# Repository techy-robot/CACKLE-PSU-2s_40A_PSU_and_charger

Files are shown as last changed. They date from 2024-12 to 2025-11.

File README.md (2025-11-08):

---
modified: 2025-11-07T22:09:08-07:00
---

# 2s 40A PSU and charger

> [!TIP]
> This board is part of a larger modular control board ecosystem, [CACKLE](https://github.com/techy-robot/CACKLE)

This is a rather complex power supply unit. It supports USB-C Power Delivery at 9volt 2 amps, and can charge a 2 cell lipo battery. It can pump out 40 amps if the battery supports the current. It also had battery protection and balancing built in, and a RS485 communication unit that can translate USB or SPI data to RS485.

The outer copper is 2oz, and the inner is 0.5 oz. Additional metal is needed to support the full current.

The main ICs on board are the TI BQ24780S battery charger, TI BQ76905 battery balancer and monitor, and a CH32X035G8U6 mcu. The system can theoretically handle 20 volt spikes, but the battery and all down line items could become damaged. I think there is also some 16v capacitors on the power lines that would be damaged. This is really meant for 9v usb-c charging to an 8.4v max lipo.

There are 2 plated through hole pads for the main battery wires, and a JST XH 3-pin connector for the balance plug in the common pin arrangement for Turnigy batteries.

The MCU has several purposes:
- Manage USB-C PD negotiations over the CC pins (built in PHY)
- Interact with the battery charger to keep it alive and change settings for charge profiles and curves
- Trigger battery balancing
- Report battery sensor data over the bus
- Act as a host adapter to convert USB or SPI data to rs485 bus commands and back. Helpful for debugging the system via a laptop, or if your main compute board needs to control the motors and sensors and doesn't have RS485 built in.

Schematic PDF

Partial 3D image, some connectors missing:
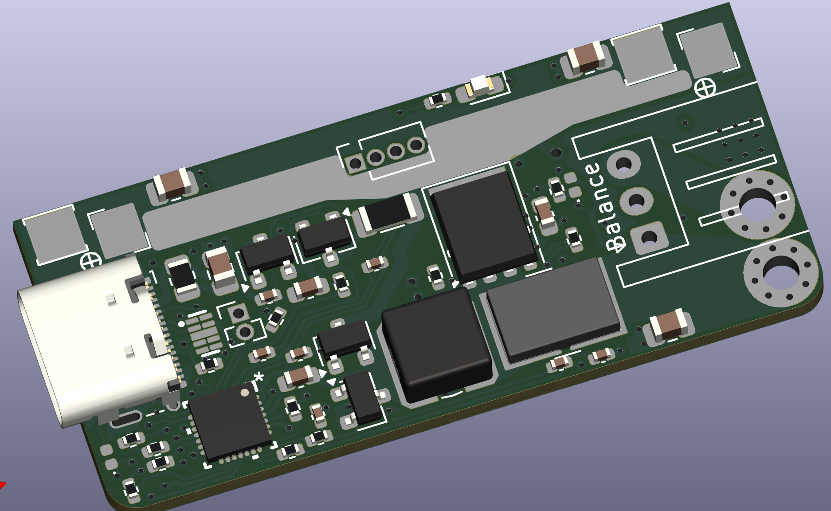
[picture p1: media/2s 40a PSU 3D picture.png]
2s 40a PSU 3D picture


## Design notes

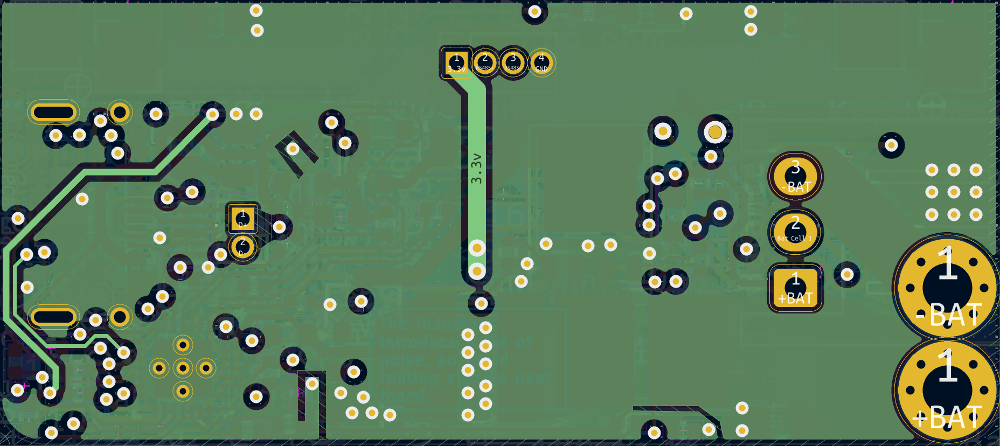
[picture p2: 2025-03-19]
media/2s 40a PSU In1.png

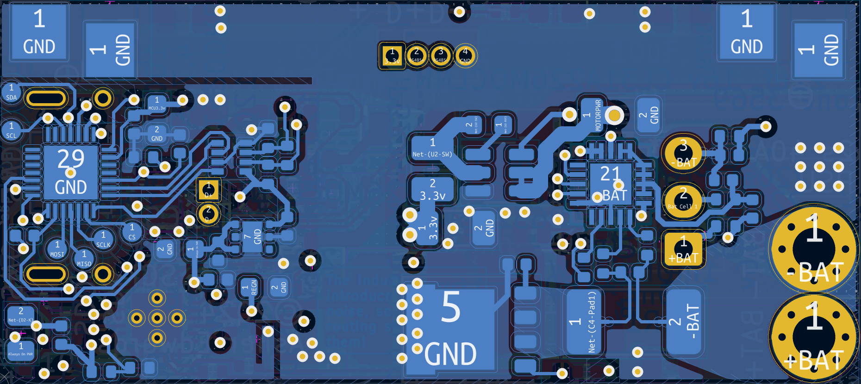
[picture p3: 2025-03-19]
media/2s 40a PSU Bottom.png

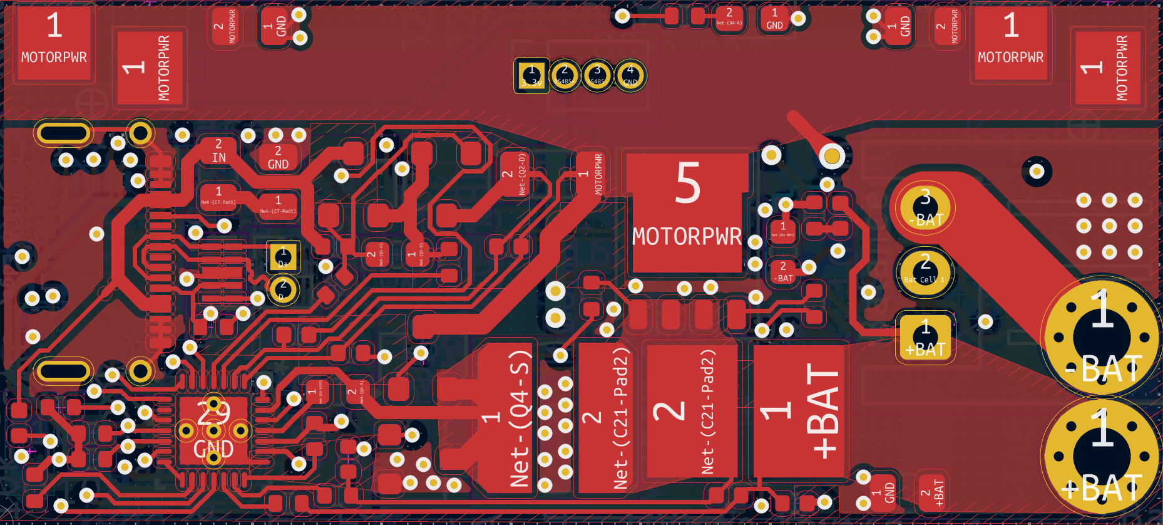
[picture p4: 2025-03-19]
media/2s 40a PSU Top.png

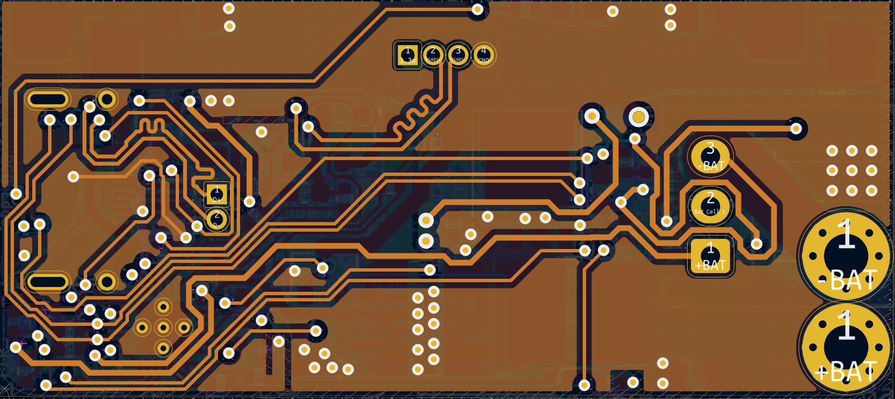
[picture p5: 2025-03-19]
media/2s 40a PSU In2.png

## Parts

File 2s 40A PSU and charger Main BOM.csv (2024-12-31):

Id | Designator | Footprint | Quantity | Designation | Supplier and ref
1 | R14 | R_2512_6332Metric_6W | 1 | 1mOhm, 6W
2 | R18 | R_Vishay_2818 | 1 | 5mOhm, 10W, 2818
3 | C9,C23,C10,C21,C11,C22,C32,C25,C4,C3 | C_0402_1005Metric | 10 | 100nF, 16v
4 | D11 | CDDFN103324P | 1 | CDDFN10-3324P
5 | R24,R20,R23,R29,R11 | R_0402_1005Metric | 5 | 10k
6 | R10,R8,R7 | R_0402_1005Metric | 3 | 4.02k
7 | C20,C12,C7,C14 | C_0805_2012Metric | 4 | 10uF, 16v
8 | R1 | R_1206_3216Metric | 1 | 10mOhm, 1W
9 | Q1,Q5,Q4,Q2 | SC-59 | 4 | PJA3430, or HL 2320A
10 | D1,D3,D2 | D_0402_1005Metric | 3 | GSDH3005
11 | R19,R6,R33 | R_0402_1005Metric | 3 | 5.1k
12 | C2,C24 | C_0603_1608Metric | 2 | 2.2uf, 16v
13 | R25 | R_0402_1005Metric | 1 | 80.6 ohm
14 | C5 | C_0402_1005Metric | 1 | 1nF, 16v
15 | J3,J1,J7,J6 | Keystone_3579 | 4 | Keystone 3579
16 | R3,R5,R4 | R_0402_1005Metric | 3 | 100ohm
17 | L2 | L_Bourns_SDR0604 | 1 | 6.8uH HPC HPC5040NF-6R8M
18 | J2 | JST_XH_S3B-XH-A_1x03_P2.50mm_Horizontal | 1 | JST XH-S Balance Plug
19 | J5,J4,J8,J9 | Keystone_3569_half | 4 | Keystone 3569
20 | J11 | PinSocket_1x04_P1.27mm_Vertical | 1 | 1.27mm 4 pin socket
21 | R2 | R_0805_2012Metric | 1 | 2ohm
22 | R21,R12,R22,R16,R17,R15 | R_0402_1005Metric | 6 | 10ohm
23 | D4 | LED_0603_1608Metric_Pad1.05x0.95mm_HandSolder | 1 | 2.6~3.1 Fv Green 5ma
24 | Q3,Q6 | PQFN-8-EP_6x5mm_P1.27mm_Generic | 2 | Vishay sir404dp, or SiR500DP
25 | U3 | RUY0028A | 1 | BQ24780SRUYR
26 | C6,C17 | C_0603_1608Metric | 2 | 47nF, 16v
27 | J10 | USB_C_G-Switch_GT-USB-7025-JLCPCBv | 1 | G-Switch-GT-USB-7025
28 | R30,R31 | R_0402_1005Metric | 2 | 866k
29 | U7 | WSON-6-1EP_2x2mm_P0.65mm_EP1x1.6mm | 1 | TPS7A2633DRV
30 | R26,R27,R28 | R_0402_1005Metric | 3 | 120 ohm
31 | C15 | C_0402_1005Metric | 1 | 1uf, 16v
32 | C28,C27 | C_1206_3216Metric | 2 | 22uf, 16v CL31A226MOCLNN
33 | C31 | C_0603_1608Metric | 1 | 10uF, 16v
34 | C40 | C_0603_1608Metric | 1 | 100nF, 16v
35 | U5 | SOT-583-8 | 1 | THVD1420DRLR
36 | C13,C19,C18 | C_0402_1005Metric | 3 | 220nF, 16v
37 | L3 | L_1008_2520Metric | 1 | 2.2uH, WIP322512A-2R2MLDG
38 | C30,C29 | C_0402_1005Metric | 2 | 100pF
39 | C33 | C_0402_1005Metric | 1 | 2.2uF, 16v
40 | U1 | VQFN20_RGR_TEX | 1 | BQ76905RGRR
41 | U6 | QFN-28-1EP_4x4mm_P0.4mm_EP2.8x2.8mm | 1 | CH32X035G8U6
42 | R9 | R_0805_2012Metric | 1 | 10ohm
43 | U2 | TSOT-23-6 | 1 | AP63203WU
44 | C26 | C_0603_1608Metric | 1 | 4.7uF, 16v

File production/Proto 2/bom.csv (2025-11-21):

Designator | Footprint | Quantity | Value | LCSC Part #
C10, C11, C21, C22, C23, C25, C3, C32, C4, C9 | 0402 | 10 | 100nF, 16v | C1525
C12, C14, C20, C7 | 0805 | 4 | 10uF, 16v | C15850
C13, C18, C19 | 0402 | 3 | 220nF, 16v | C16772
C15 | 0402 | 1 | 1uf, 16v | C52923
C17, C6 | 0603 | 2 | 47nF, 16v | C1622
C2, C24 | 0603 | 2 | 2.2uf, 16v | C23630
C26 | 0603 | 1 | 4.7uF, 16v | C19666
C27, C28 | 1206 | 2 | 22uf, 16v CL31A226MOCLNN | C159758
C29, C30 | 0402 | 2 | 100pF | C1546
C31 | 0603 | 1 | 10uF, 16v | C96446
C33 | 0402 | 1 | 2.2uF, 16v | C12530
C40 | 0603 | 1 | 100nF, 16v | C14663
C5 | 0402 | 1 | 1nF, 16v | C1523
D1, D2, D3 | 0402 | 3 | GSDH3005 | C2837790
D11 | CDDFN103324P | 1 | CDDFN10-3324P | C913227
D4 | 0603 | 1 | 2.6~3.1 Fv Green 5ma | C3028858
J1, J3, J6, J7 | Keystone_6100 | 4 | Keystone 6100
J10 | USB_C_G-Switch_GT-USB-7025-JLCPCBv | 1 | G-Switch-GT-USB-7025 | C963213
J13 | Precidip 853-87-004-20-001101 | 1 | Precidip 853-87-004-20-001101
J2 | JST_XH_S3B-XH-A_1x03_P2.50mm_Horizontal | 1 | JST XH-S Balance Plug | C161860
J4, J5, J8, J9 | Keystone_6102 | 4 | Keystone 6102
L2 | L_Bourns_SDR0604 | 1 | 6.8uH HPC HPC5040NF-6R8M | C357072
L3 | 1008 | 1 | 3.3uH | C2041573
Q1, Q2, Q4, Q5 | SC-59 | 4 | PJA3430, or HL 2320A | C7437078
Q3, Q6 | PQFN-8-EP_6x5mm_P1.27mm_Generic | 2 | Vishay sir404dp, or SiR500DP | C3289487
R1 | 1206 | 1 | 10mOhm, 1W | C473031
R10, R7, R8 | 0402 | 3 | 4.02k | C43251
R11, R13, R20, R23, R24, R29, R32 | 0402 | 7 | 10k | C25744
R12, R15, R16, R17, R21, R22 | 0402 | 6 | 10ohm | C25077
R14 | 2512 | 1 | 1mOhm, 6W | C19270875
R18 | R_Vishay_2818 | 1 | 5mOhm, 10W, 2818 | C2090564
R19, R33, R6 | 0402 | 3 | 5.1k | C25905
R2 | 0805 | 1 | 2ohm | C17521
R25 | 0402 | 1 | 80.6 ohm | C185392
R26, R27, R28 | 0402 | 3 | 120 ohm | C25079
R3, R4, R5 | 0402 | 3 | 100ohm | C25076
R30, R31 | 0402 | 2 | 866k | C137931
R9 | 0805 | 1 | 10ohm | C17415
SW1 | R-667995_MIT | 1 | Mitsumi R-667996 | C4365007
U1 | VQFN20_RGR_TEX | 1 | BQ76905RGRR | C22394458
U2 | TSOT-23-6 | 1 | AP63203WU | C780769
U3 | RUY0028A | 1 | BQ24780SRUYR
U5 | SOT-583-8 | 1 | THVD1420DRLR
U6 | QFN-28-1EP_4x4mm_P0.4mm_EP2.8x2.8mm | 1 | CH32X035G8U6 | C7437027
U7 | WSON-6-1EP_2x2mm_P0.65mm_EP1x1.6mm | 1 | TPS7A2633DRV | C2876256

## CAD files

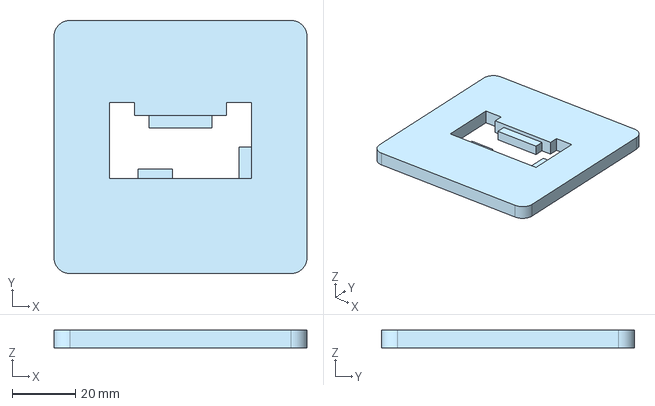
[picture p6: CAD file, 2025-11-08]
2s 40amp PSU 2nd side Stencil Jig.step
80.0 x 80.0 x 5.60 mm

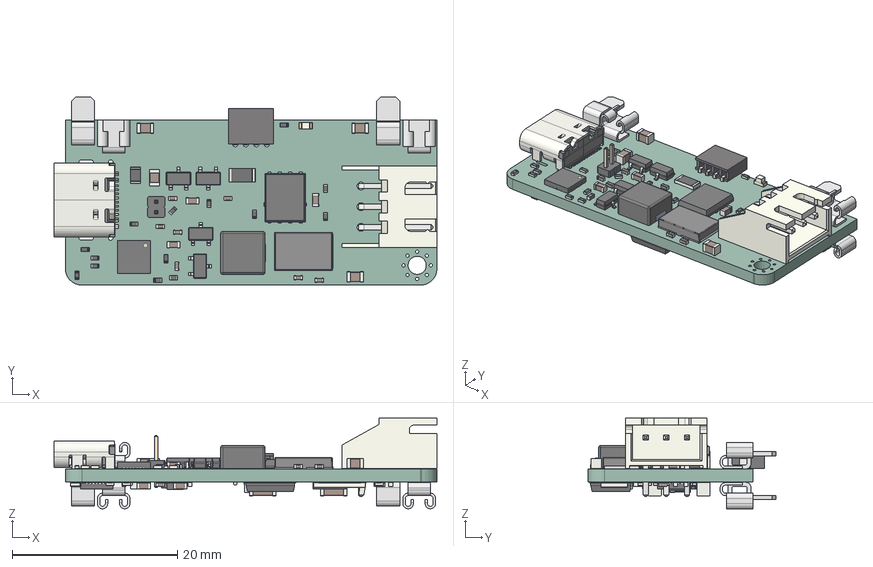
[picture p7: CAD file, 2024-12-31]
2s 40A PSU and charger.step
46.4 x 22.8 x 11.0 mm
C_0402_1005Metric x 18
R_0402_1005Metric x 26
C_0805_2012Metric x 4
R_1206_3216Metric
SC_59 x 4
C_0603_1608Metric x 7
Keystone 3579 x 4
WSHM2818
CQ assembly
JST_S3B_XH_A
Keystone 3569 half x 4
BD090-04-A-L-G
R_0805_2012Metric x 2
PinHeader_1x02_P127mm_Vertical
LED_0603_1608Metric
Vishay_PowerPAK_SO-8 x 2
QFN-28-1EP_4x4mm_Pitch0.4mm x 2
USB_C_Receptacle_16P_TopMnt_Horizontal_GCT_USB4105-xx-A
WSON_6_1EP_2x2mm_P065mm_EP1x16mm
C_1206_3216Metric x 2
SOT_563
L_1008_2520Metric
R_2512_6332Metric
QFN-20-1EP_4x4mm_Pitch0.5mm
TSOT_23_6
_autosave-2s 40A PSU and charger_PCB

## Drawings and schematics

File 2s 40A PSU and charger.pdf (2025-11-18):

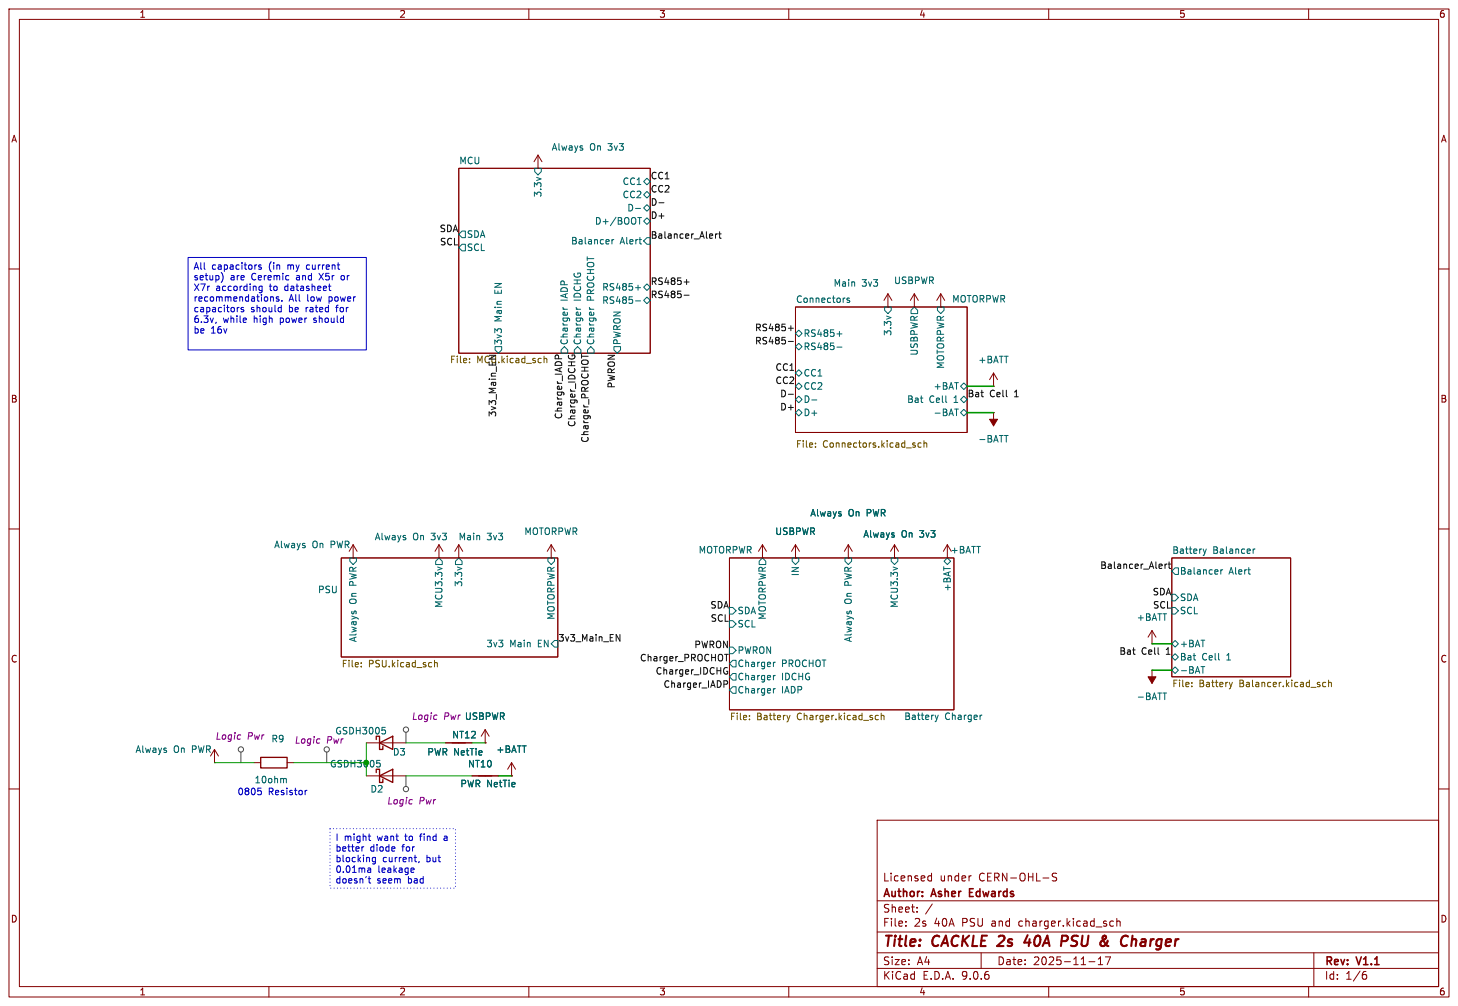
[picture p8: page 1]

D+/BOOT CC2 D- CC1 3v3 Main EN MCU

+BATT Main 3v3 Always On PWR

-BATT Always On 3v3 Main 3v3 D3 GSDH3005 D2 GSDH3005

Always On PWR MOTORPWR

Charger PROCHOT Charger IADP Charger IDCHG

I might want to find a

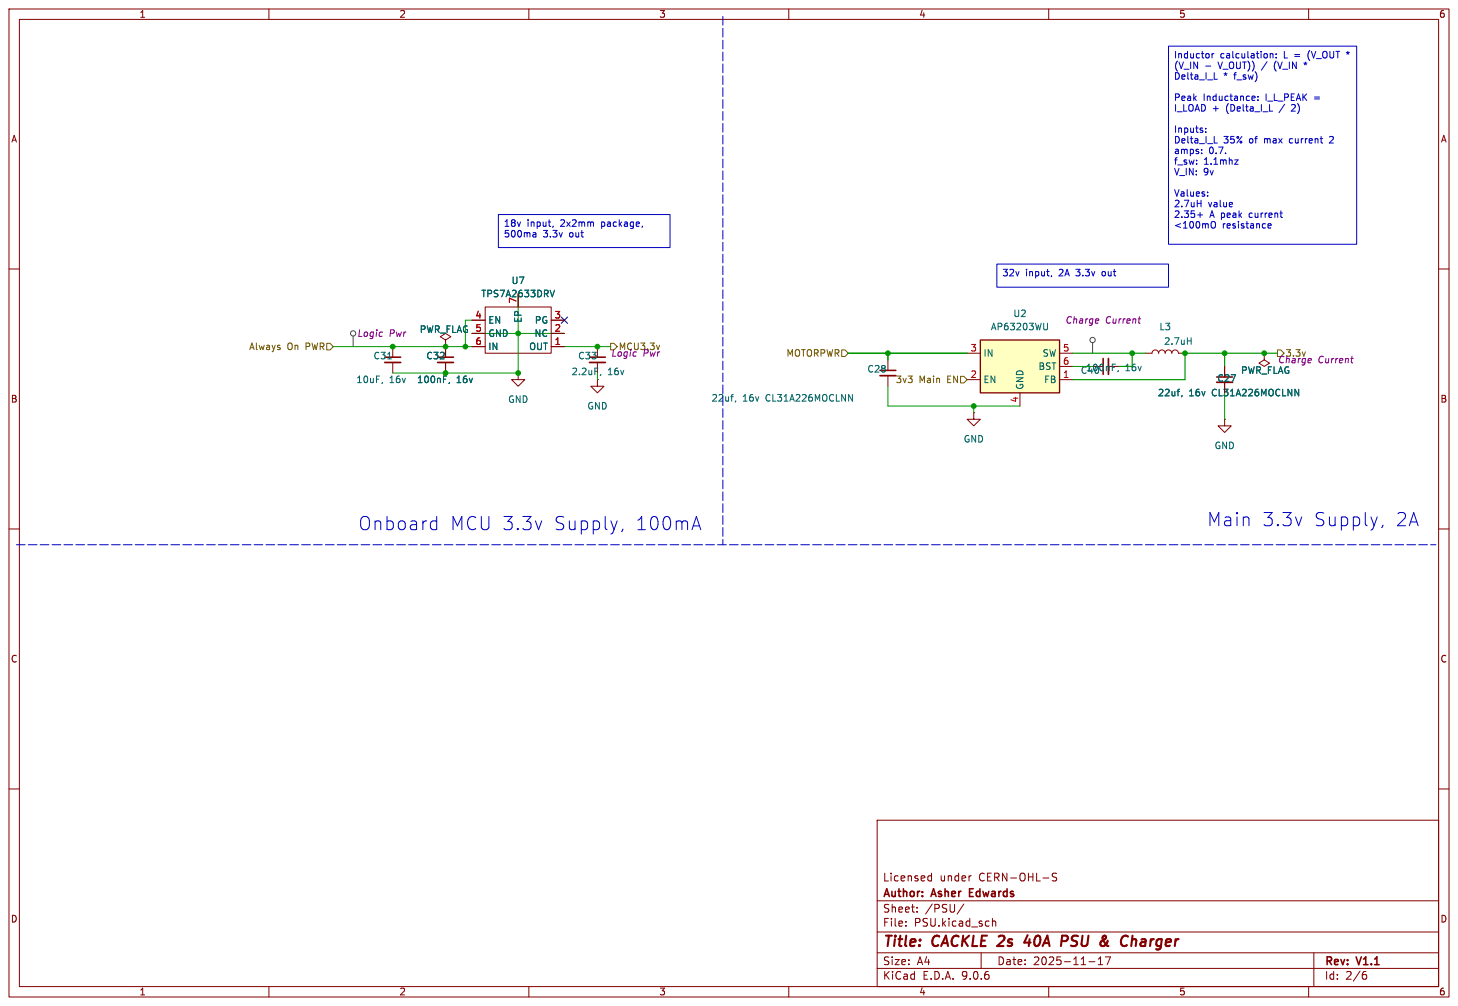
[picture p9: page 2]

Inputs: Delta_I_L 35% of max current 2

3.3v Charge Current MOTORPWR MCU3.3v Logic Pwr Always On PWR

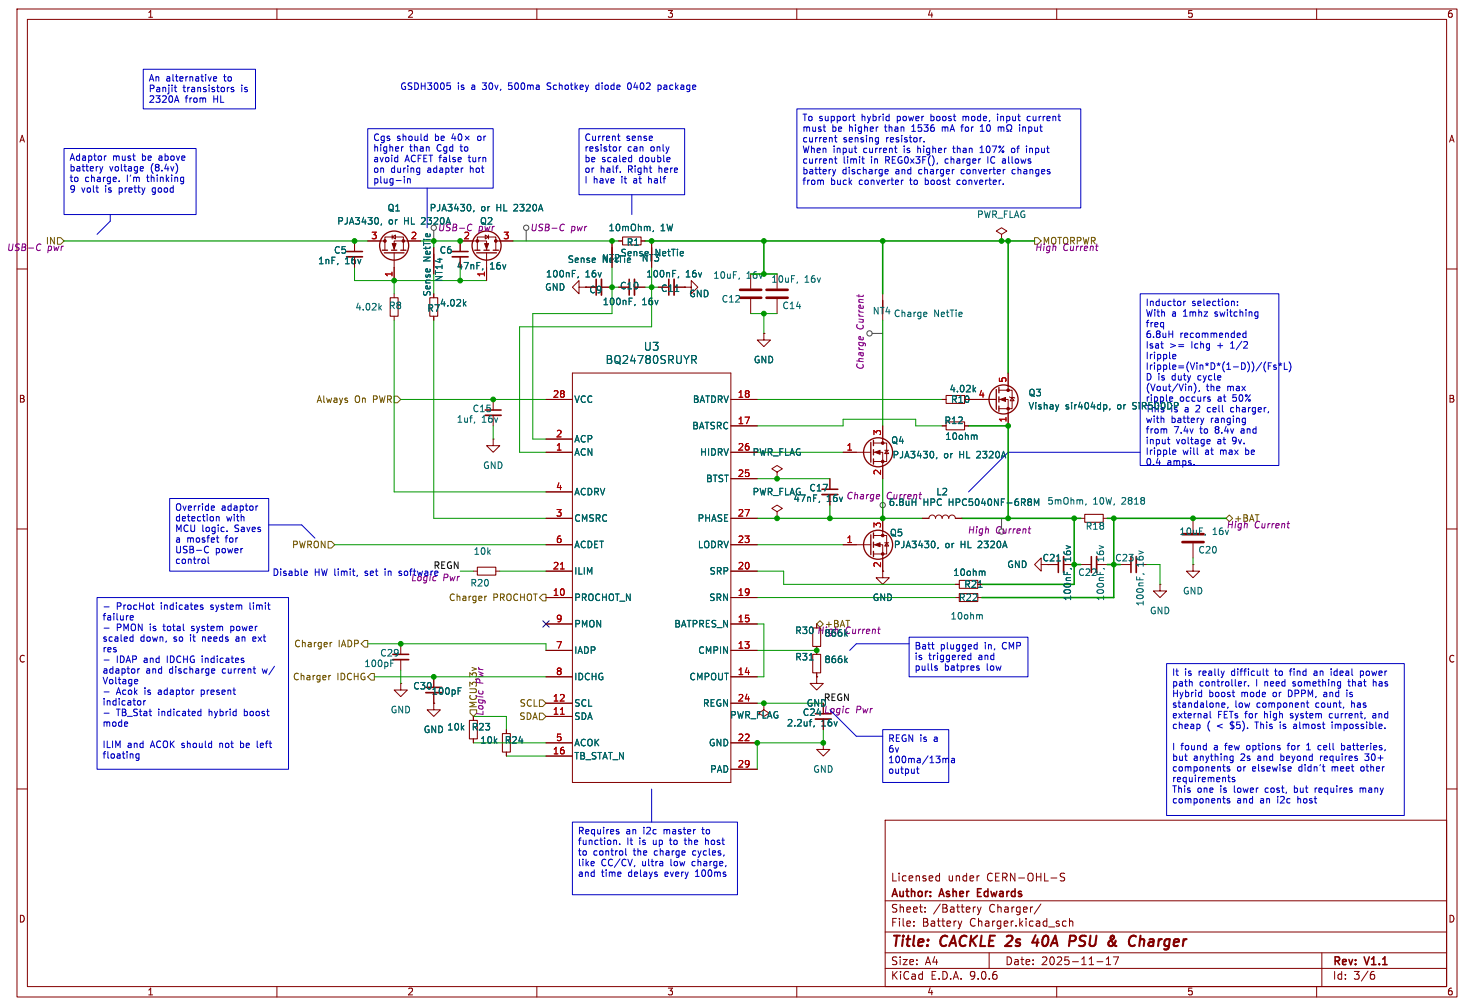
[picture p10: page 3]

I have it at half Requires an i2c master to

0.4 amps. Cgs should be þÿ40×or higher than Cgd to

Adaptor must be above
battery voltage (8.4v)
to charge. I'm thinking

avoid ACFET false turn
on during adapter hot plug-in
LODRV 23 SRP 20 SRN 19 BATPRES_N 15 CMPIN 13 CMPOUT 14 REGN 24 GND 22 PAD 29 HIDRV 26 U3 BQ24780SRUYR

or half. Right here

3 2 Q4PJA3430, or HL 2320A NT4 Charge NetTie C6

freq
6.8uH recommended
Isat >= Ichg + 1/2
Iripple
Iripple=(Vin*D*(1-D))/(Fs*L) D is duty cycle

ripple occurs at 50%
This is a 2 cell charger, with battery ranging

from 7.4v to 8.4v and
input voltage at 9v.
Iripple will at max be

failure
- PMON is total system power scaled down, so it needs an ext res

Charger IADP Charger IDCHG

- Acok is adaptor present
indicator

cheap ( < $5). This is almost impossible.

ILIM and ACOK should not be left

requirements This one is lower cost, but requires many

like CC/CV, ultra low charge, and time delays every 100ms

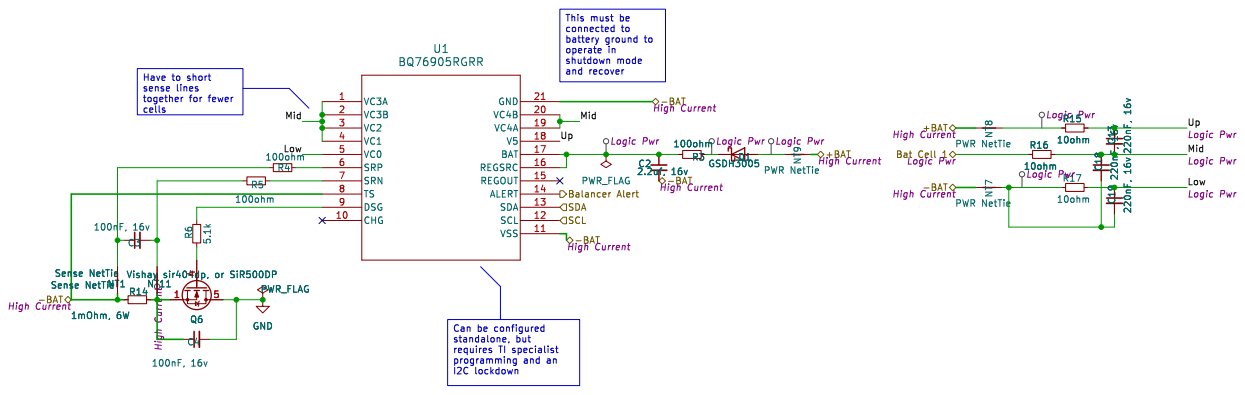
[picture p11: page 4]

Logic Pwr Mid UpThis must be
battery ground to
operate in
shutdown mode

and recover Have to short sense lines

Logic Pwr

Logic Pwr Logic Pwr Logic Pwr High Current

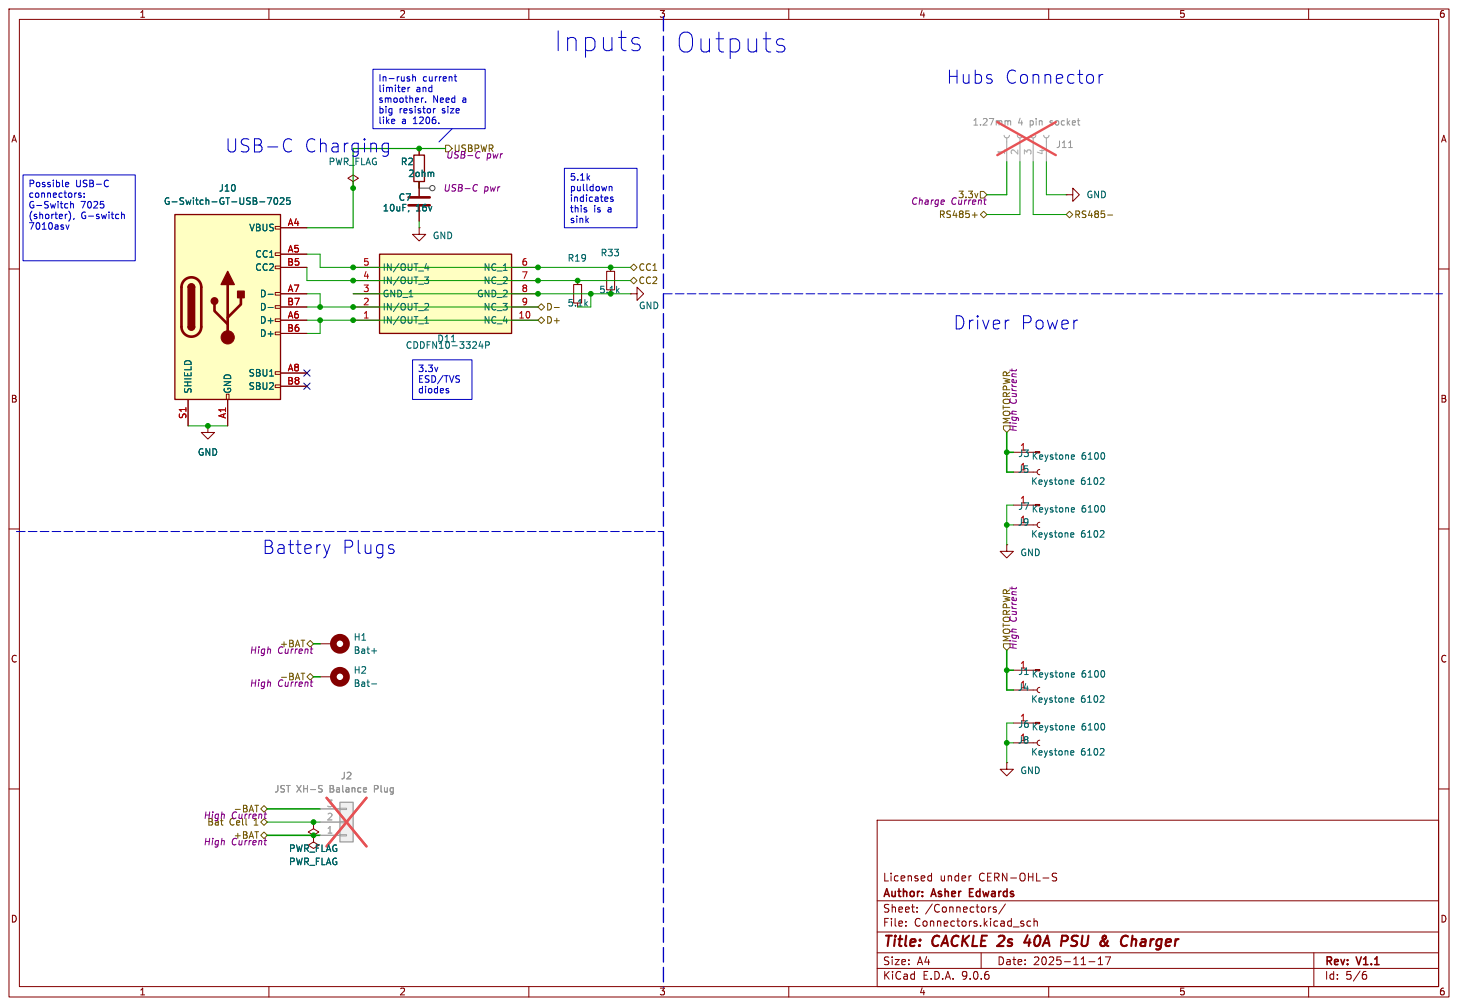
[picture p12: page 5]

J10 G-Switch-GT-USB-7025 GND

J7 Keystone 6100 1
J1 Keystone 6100 GND 1J8 Keystone 6102 GND 1

JST XH-S Balance Plug 123 PWR_FLAG

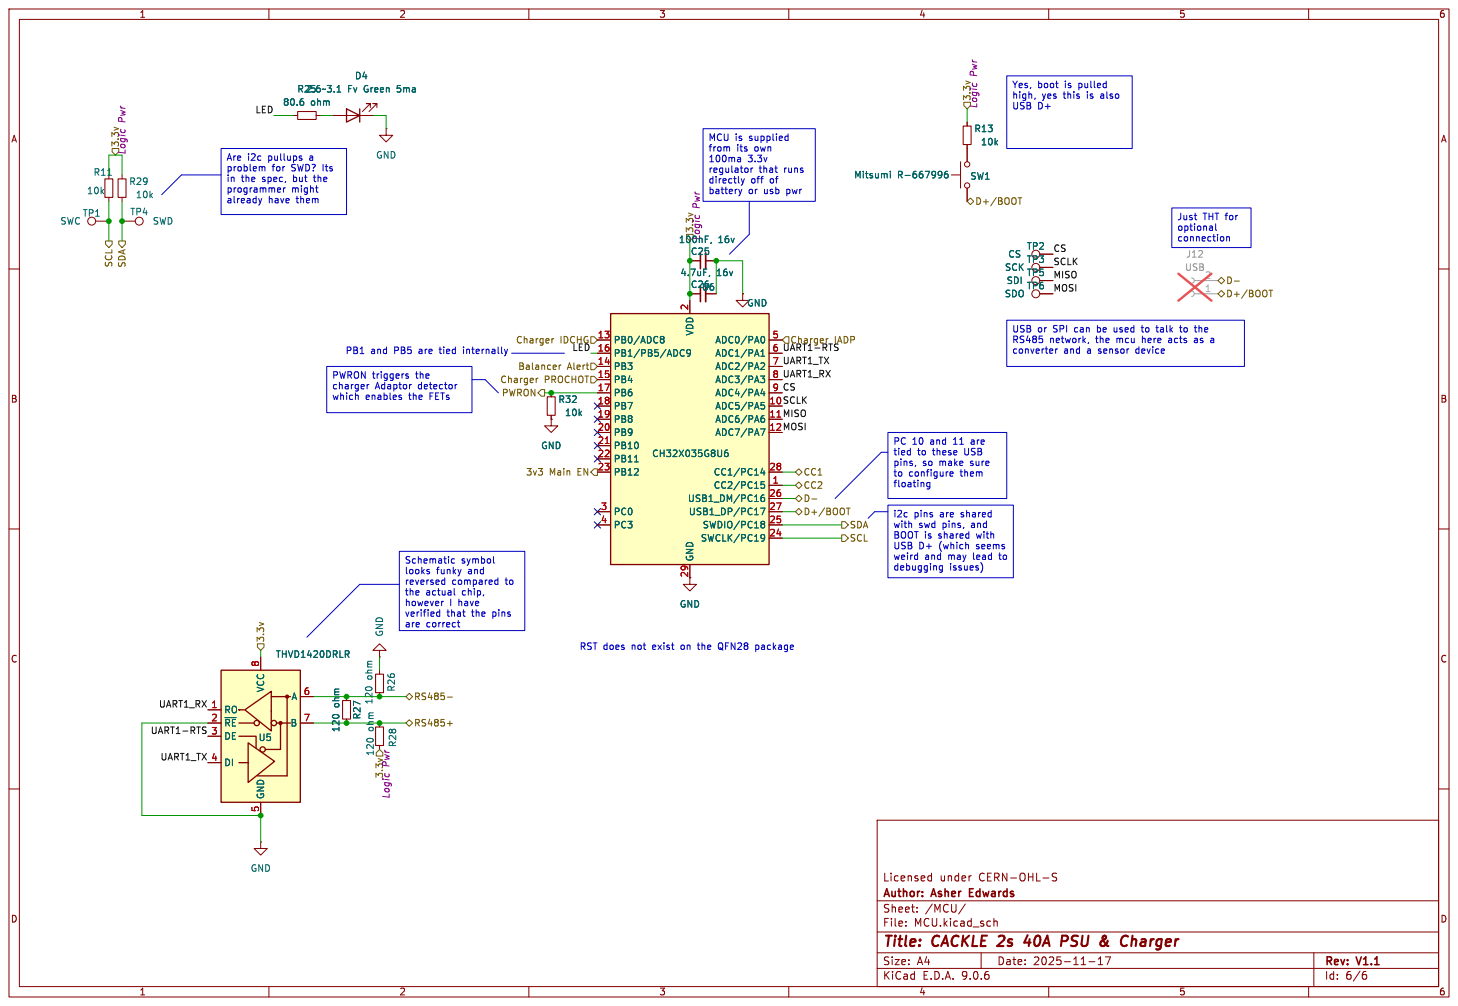
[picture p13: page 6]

Yes, boot is pulled
high, yes this is also USB D+ USB or SPI can be used to talk to the RS485 network, the mcu here acts as a

problem for SWD? Its
in the spec, but the
already have them

2 GND 29 ADC0/PA0 5 ADC1/PA1 6 ADC2/PA2 7 ADC3/PA3 8 ADC4/PA4 9 ADC5/PA5 10 ADC6/PA6 11 ADC7/PA7 12 CC1/PC14 28 CC2/PC15 1 USB1_DM/PC16 26 USB1_DP/PC17 27 SWDIO/PC18 25 SWCLK/PC19 24 U6 CH32X035G8U6 GND

2 GND 29 ADC0/PA0 5 ADC1/PA1 6 ADC2/PA2 7 ADC3/PA3 8 ADC4/PA4 9 ADC5/PA5 10 ADC6/PA6 11 ADC7/PA7 12 CC1/PC14 28 CC2/PC15 1 USB1_DM/PC16 26 USB1_DP/PC17 27 SWDIO/PC18 25 SWCLK/PC19 24 GND

tied to these USB
pins, so make sure
floating

i2c pins are shared with swd pins, and BOOT is shared with USB D+ (which seems weird and may lead to

looks funky and
the actual chip, however I have

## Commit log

2024-12-31 Rearranged design files
    Instead of "Kicad" the main design folder is now named "Hardware" since I have gerbers and notes besides the kicad files. I have also put my designs in their proper categories.
    [2s 40A PSU and charger Main BOM.csv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]
2025-01-01 Updated files for JLC DFM checks
    [2s 40A PSU and charger.kicad_pcb, Battery Balancer.kicad_sch, Battery Charger.kicad_sch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]
2025-01-02 Added schematic PDFs for all boards
    [2s 40A PSU and charger.kicad_pcb, 2s 40A PSU and charger.kicad_sch, Battery Balancer.kicad_sch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]
2025-01-04 Added gerber zip files
2025-01-12 Fixed issue with USB-C pad spacing on 2oz copper
    The minimum spacing between tracks on 2oz copper is 0.16mm, and I had explicitly ignored the USB-C connector pin spacing 0.12mm in a custom DRC rule, which turned out to be a problem. I removed that rule and modified the USB-C connector pads to be slightly narrower to give more gap.
    [2s 40A PSU and charger-B_Cu.gbl, 2s 40A PSU and charger-B_Mask.gbs, 2s 40A PSU and charger-B_Paste.gbp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]
2025-01-13 Changed link names for schematic embeds not displayin
    In Obsidian I can see the pdf embeds perfectly fine, but Github doesn't want to show embedded PDFs. I changed the link alias to "Schematic PDF" so people know what the link is when it doesn't display
2025-10-10 Moved all current production files to Proto 1.
    I haven't made a 2nd prototype yet
    [2s 40A PSU and charger-B_Cu.gbl, 2s 40A PSU and charger-B_Mask.gbs, 2s 40A PSU and charger-B_Paste.gbp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]
2025-11-08 Moved stencil jig from monorepo to here
    [2s 40amp PSU 2nd side Stencil Jig.step]
2025-11-17 Clarified top level schematic
    [2s 40A PSU and charger.kicad_sch]
2025-11-17 Updated to kicad 9
    [Battery Balancer.kicad_sch, Battery Charger.kicad_sch, Connectors.kicad_sch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]
2025-11-17 Updated power connectors
    [Connectors.kicad_sch]
2025-11-17 Added inducter calculations and changed value
    My initial calculations were a bit off!
    [PSU.kicad_sch]
2025-11-18 Added MCU boot button, 3v3 power enable, and pulldown on adaptor enable
    [2s 40A PSU and charger.kicad_sch, Battery Charger.kicad_sch, MCU.kicad_sch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]
2025-11-18 Added pdf schematics
    [MCU.kicad_sch]
2025-11-18 Updated pcb to latest kicad version
    [2s 40A PSU and charger.kicad_pcb]
2025-11-18 Revert update of pmosfets with large pad 5
    [Battery Balancer.kicad_sch, Battery Charger.kicad_sch]
2025-11-18 Started layout of new components
    [2s 40A PSU and charger.kicad_pcb]
2025-11-18 Re order LED and enable pins
    [MCU.kicad_sch]
2025-11-18 Finished reroute and placement
    [2s 40A PSU and charger.kicad_pcb, MCU.kicad_sch]
2025-11-18 Fixed silkscreen
    [2s 40A PSU and charger.kicad_pcb]
2025-11-18 Corrected hub connector
    [Connectors.kicad_sch]
2025-11-18 Arranged power connectors
    [2s 40A PSU and charger.kicad_pcb]
2025-11-18 Fixed exposed mask
    [2s 40A PSU and charger.kicad_pcb]
2025-11-18 Finished design & silk
    [2s 40A PSU and charger.kicad_pcb]
2025-11-18 Production files
    [bom.csv, designators.csv, positions.csv]
2025-11-21 Replaced inductor value and lcsc part
    [2s 40A PSU and charger.kicad_pcb, PSU.kicad_sch, bom.csv]
